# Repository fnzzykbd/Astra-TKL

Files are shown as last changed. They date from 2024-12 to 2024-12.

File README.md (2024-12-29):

# Astra TKL
This is a keyboard design I've made in 2023. It's called Astra because I like space stuff. Top mount WKL TKL, 8° typing angle, 17mm front height (~18mm on inner edge, ~19mm with bumpons). The intended purpose was to make a one-off and then release it to the public once ready. The one-off had a few kinks, however, and another proto means spending more money.

This release includes the original prototyped design with one tweak (see design history), a fully updated design that would've been the second protoype (one day!) and naturally, since this is an open source release, the Fusion 360 .f3d source files with complete history for both versions.

Feel free to use the files to your hearts content in accordance with the license. I am not liable for anything, files are provided as is.

And since I am a curious fellow, if you do something with these files and order something, would be cool to let me know on Discord @fnzzy.
***
DESIGN HISTORY

Prototype was made with top mount + O-ring mount. Case bottom design didn't allow for the O-ring to work, forgot to check. My bad. The prototype had a ping issue due to a slightly warped top case, so I've used it with either the four corner screws only or with heavy force break. Doing either made it sound great.

Provided prototype files have the O-ring mount removed, since it didn't work, everything else is unchanged.

Provided updated design also removed the four centre screws as those made the prototype ping and didn't contribute to the assembly in any critical way. Some internal radii on the weight and the surrounding dish have been changed. Cable channel has been widened and chamfer adjusted to match with other internal chamfers. The updated design has not yet been prototyped.
***
The keyboard has been designed around and proven to work with the [Lysol XYZ DBoard](https://github.com/lyso1/Lysol-XYZ-DBoard) and the [daji Otus Engineering 87.5 1.2mm PCB](https://dajikeyboards.com/products/otus-engineering-87-5-pcb). If you're using another PCB, please make sure it fits.

Special thanks to ankit for providing me with free daughterboards to use with this board. Absolute legend considering that I am a complete stranger to him.

| Part  | Link |
| --- | --- |
| Case screw M3x10mm low profile  | https://www.mcmaster.com/products/screws/socket-head-screws~/thread-size~m3/length~10-mm/  |
| Plate screw M2.5x5mm | https://www.mcmaster.com/products/screws/socket-head-screws~/thread-size~m3/length~5-mm/  |
| Weight screw M3x6mm countersink | https://www.mcmaster.com/products/screws/flat-head-screws~/thread-size~m3/length~6-mm/  |
| Toblerone screw M2.5x6mm countersink | https://www.mcmaster.com/products/screws/flat-head-screws~/length~6-mm/thread-size~m2-5/  |
| Daughterboard screw M3x4mm ultra low profile | https://www.mcmaster.com/products/screws/socket-head-screws~/thread-size~m3/length~4-mm/socket-head-profile~ultra-low/  |
| Bumpons | SJ5302, Bumpon hole is 8.3mm to fit my Unikorn style bumpons I got off aliexpress, which I measured. You might see some gaps around a 3M 8mm Bumpon |

***

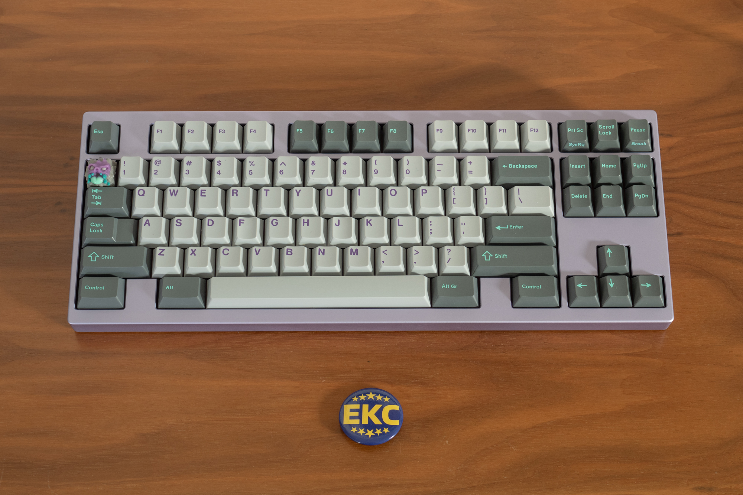
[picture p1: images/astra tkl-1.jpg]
astra-1

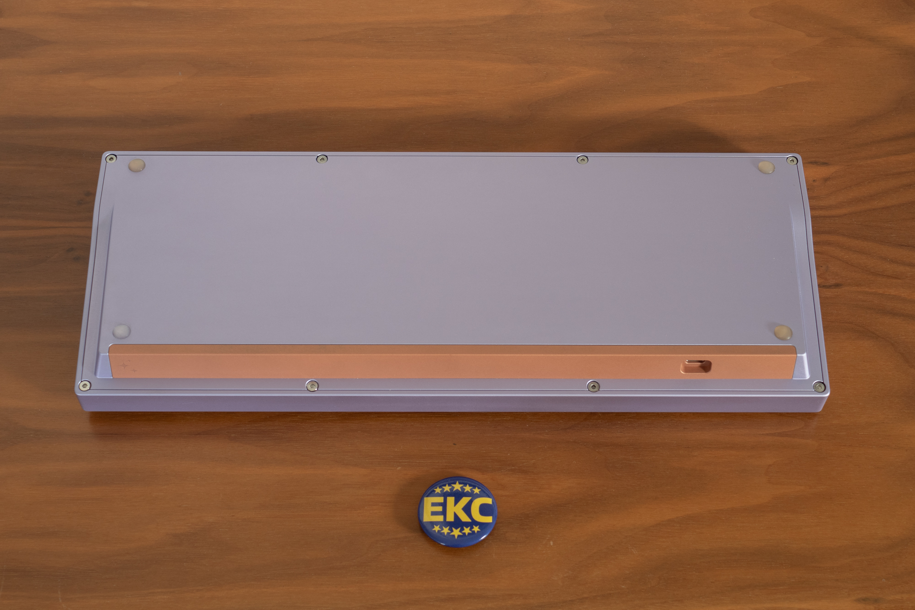
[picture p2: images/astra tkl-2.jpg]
astra-2

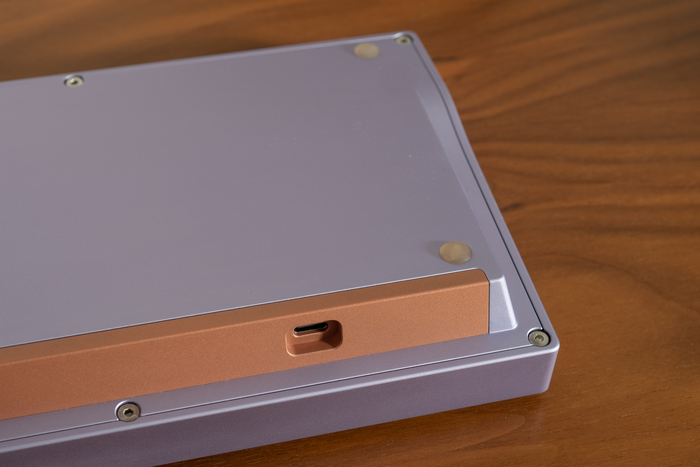
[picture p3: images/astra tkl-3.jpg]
astra-3

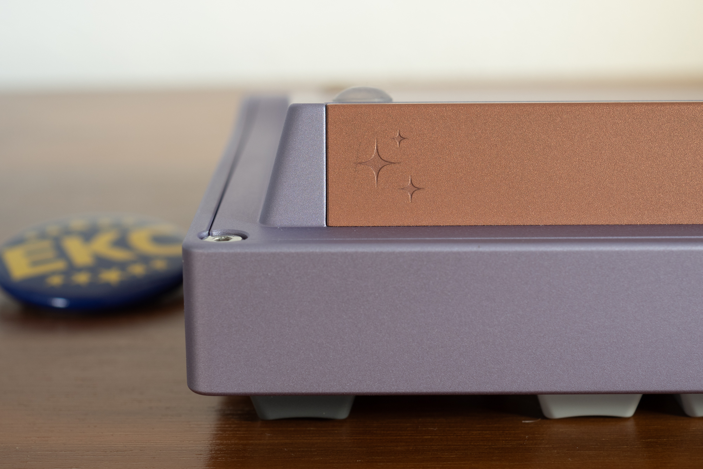
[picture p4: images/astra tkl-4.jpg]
astra-4

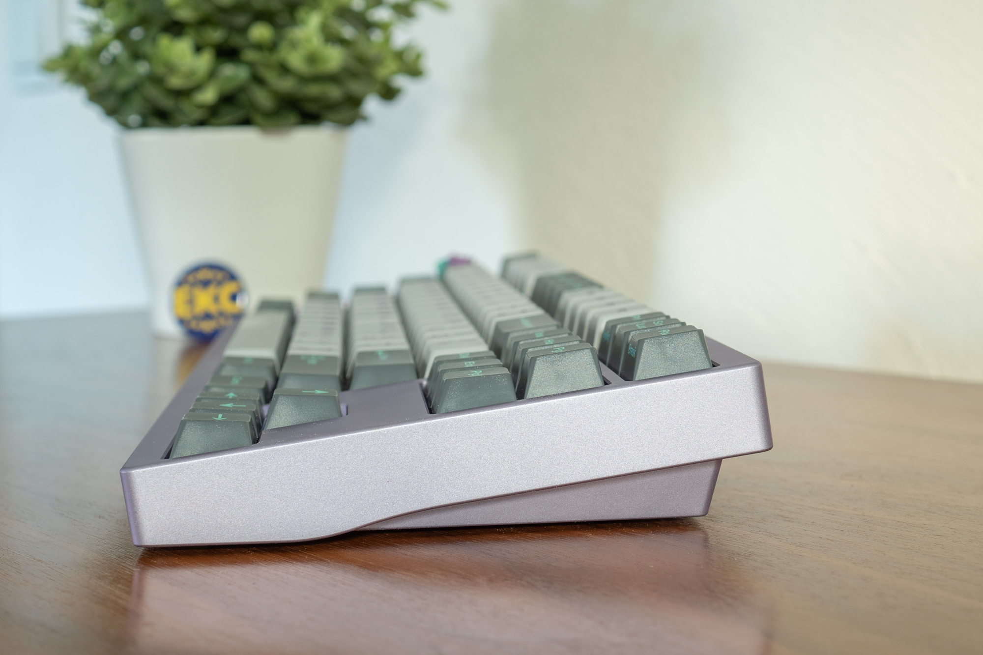
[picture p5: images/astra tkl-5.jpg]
astra-5

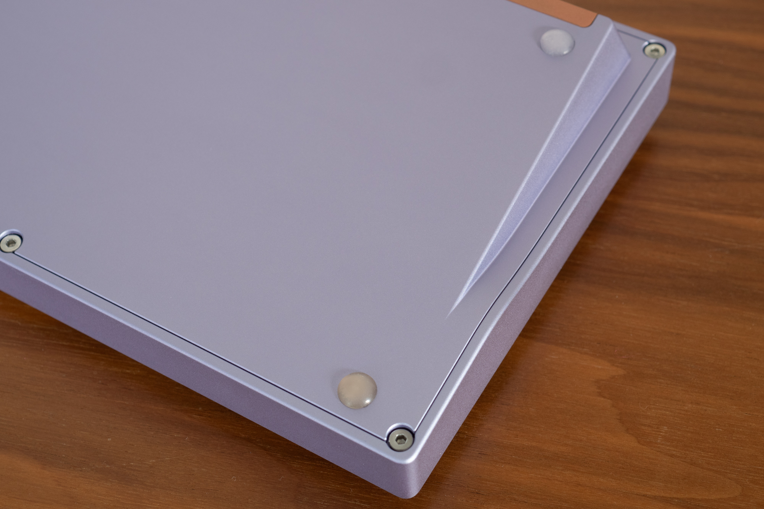
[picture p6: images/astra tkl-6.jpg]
astra-6

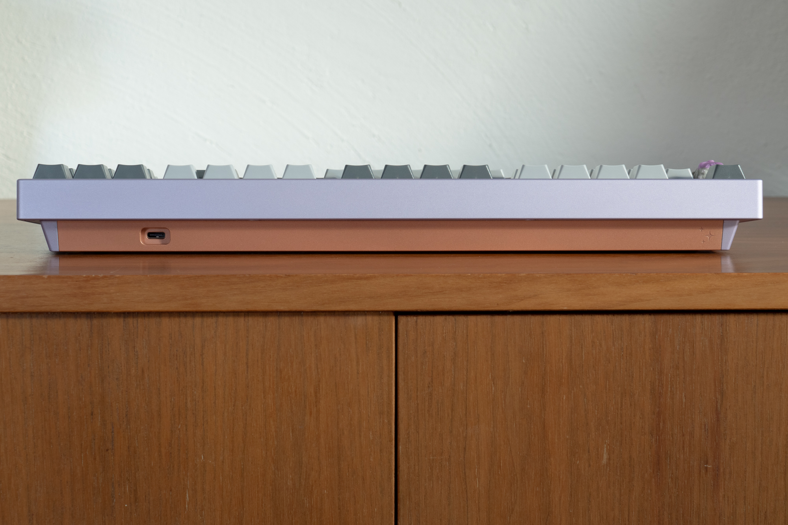
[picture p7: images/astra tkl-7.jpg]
astra-6

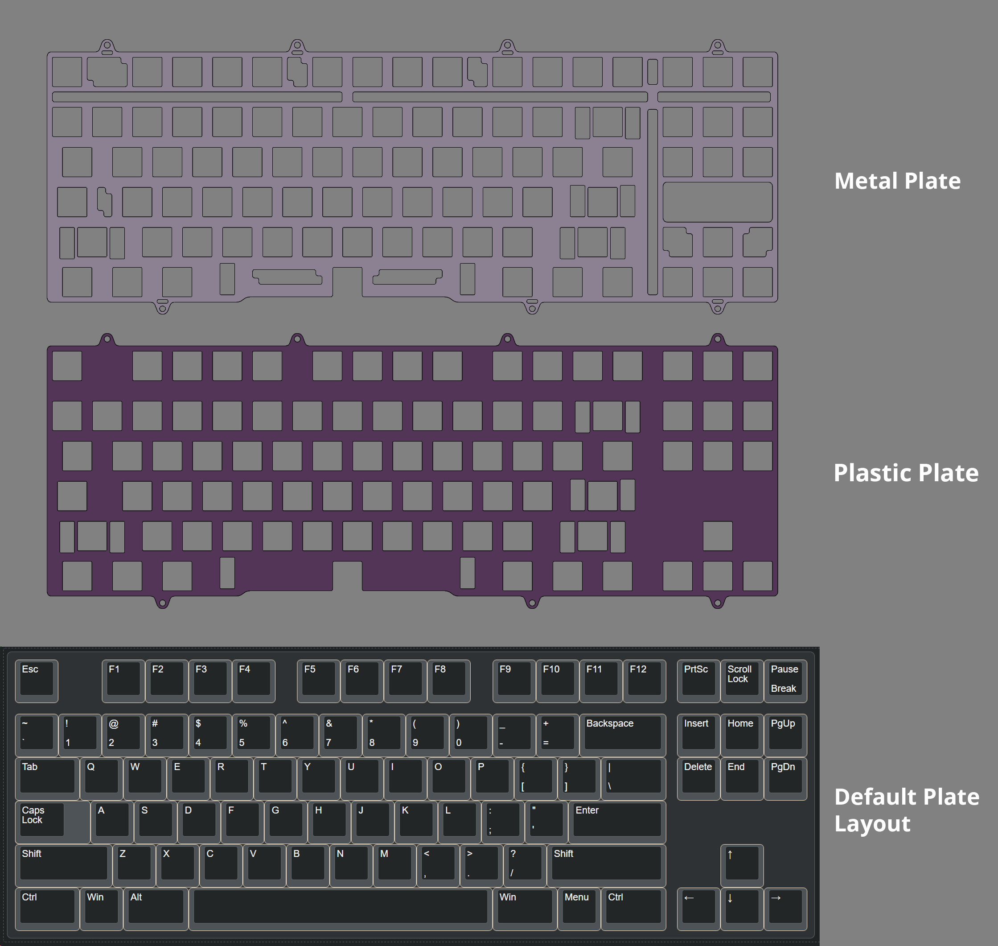
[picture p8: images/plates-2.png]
plates

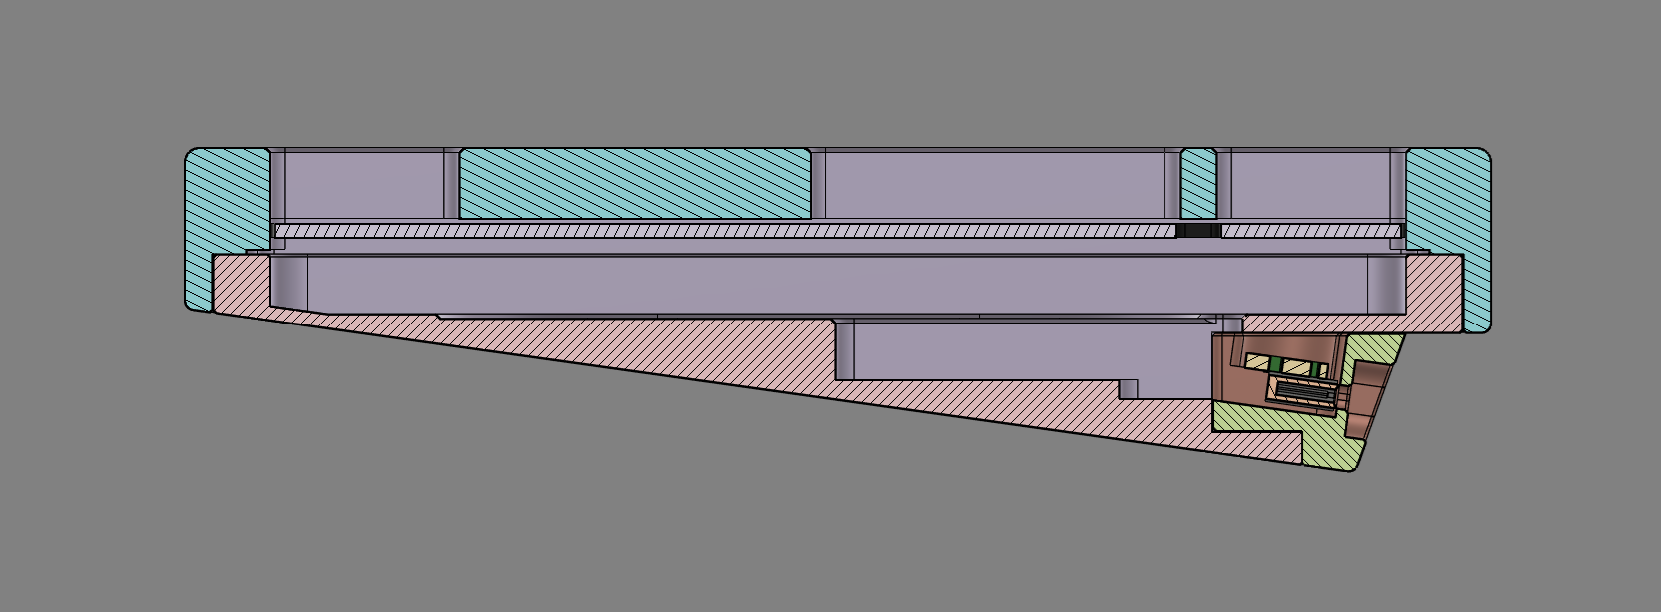
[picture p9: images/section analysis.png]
section


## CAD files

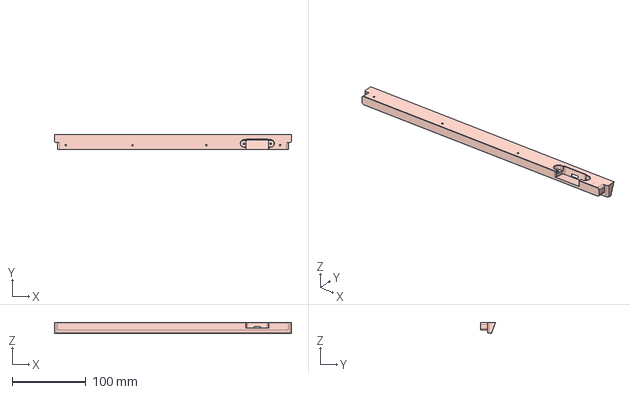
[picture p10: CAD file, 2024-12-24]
Original Prototype/ASTRA_TOBLERONE_COPPER.step
321.2 x 20.3 x 14.6 mm

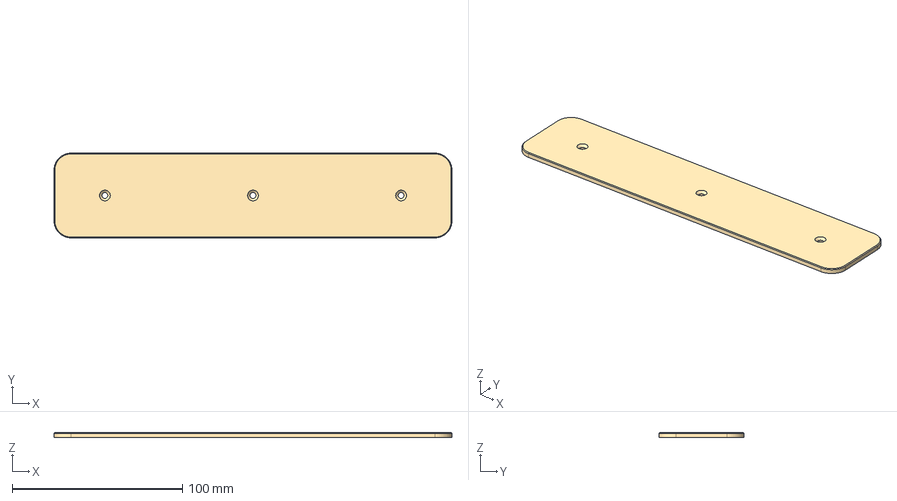
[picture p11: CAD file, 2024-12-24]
Updated Revision/Astra_weight_inner.step
233.7 x 49.8 x 3.00 mm

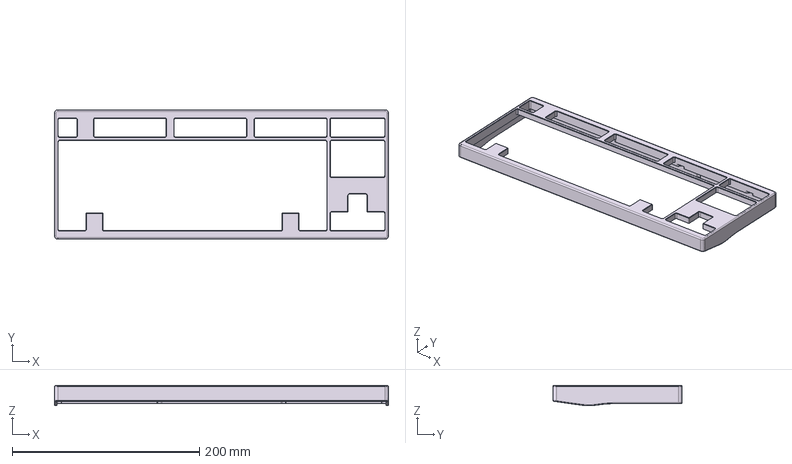
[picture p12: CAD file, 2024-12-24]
Original Prototype/ASTRA_TOP.step
356.6 x 138.0 x 21.9 mm

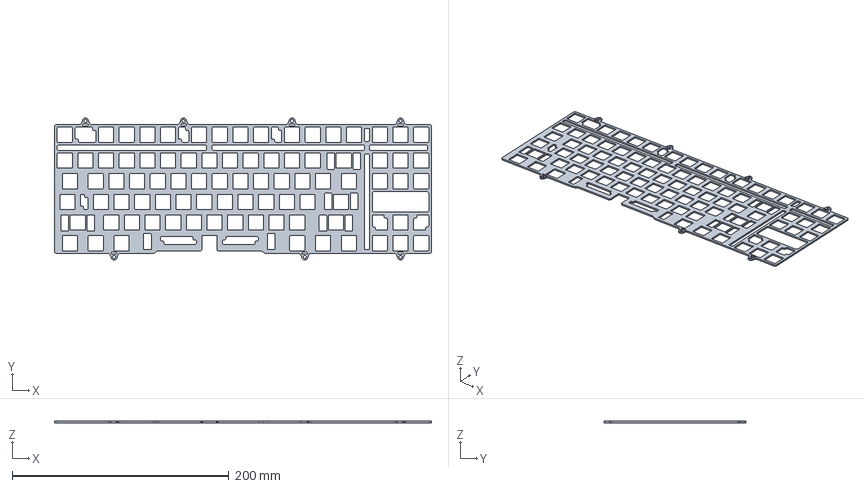
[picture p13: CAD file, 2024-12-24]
Original Prototype/ASTRA_PLATE_ALU5052.step
347.7 x 131.0 x 1.50 mm

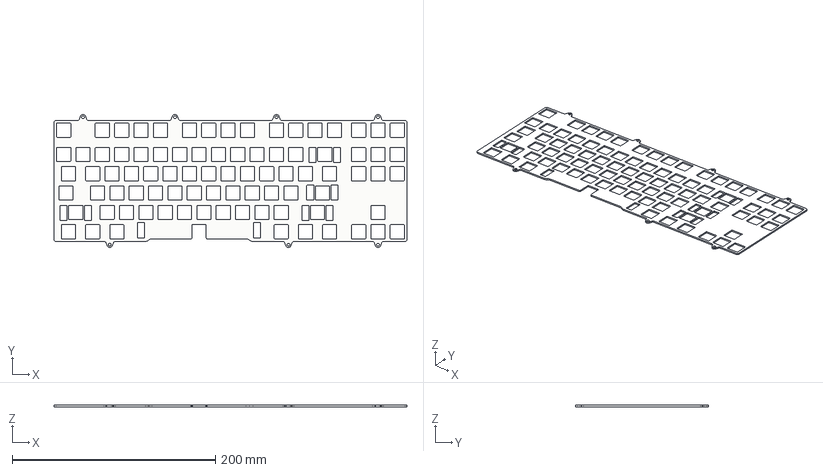
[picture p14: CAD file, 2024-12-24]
Updated Revision/Astra_plate_plastic.step
347.7 x 131.0 x 1.50 mm

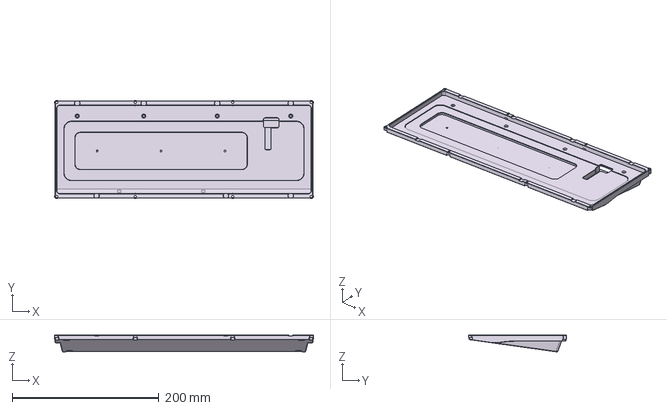
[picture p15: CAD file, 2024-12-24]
Original Prototype/ASTRA_BOTTOM.step
352.4 x 133.8 x 23.0 mm

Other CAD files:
Original Prototype/ASTRA_WEIGHT_BRASS.step
Updated Revision/Astra_toblerone.step
Updated Revision/Astra_top.step
Updated Revision/Astra_plate_metal.step
Original Prototype/ASTRA_PLATE_PC.step
Updated Revision/Astra_bottom.step

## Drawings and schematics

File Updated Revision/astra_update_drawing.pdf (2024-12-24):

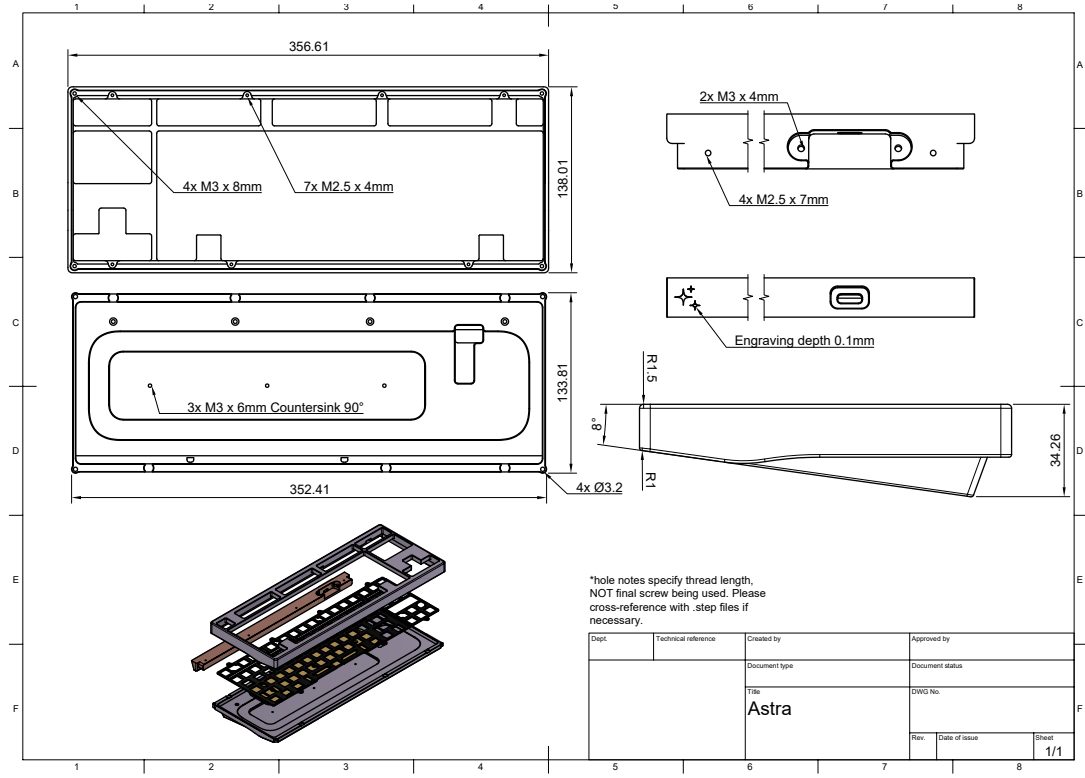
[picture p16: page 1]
8 BCDEF; ABCDEF Dept.; Technical reference; Created by; Approved by Document type; Document status Title; DWG No. Rev.; Date of issue; Sheet 1/1 Astra ³⁵⁶.61; 34.26 3x M3 x 6mm Countersink 90° 2x M3 x 4mm 4x Ø3.2; R1.5 R1 Engraving depth 0.1mm

133.81 352.41 4x M2.5 x 7mm *hole notes specify thread length,

NOT final screw being used. Please
cross-reference with .step files if
necessary.

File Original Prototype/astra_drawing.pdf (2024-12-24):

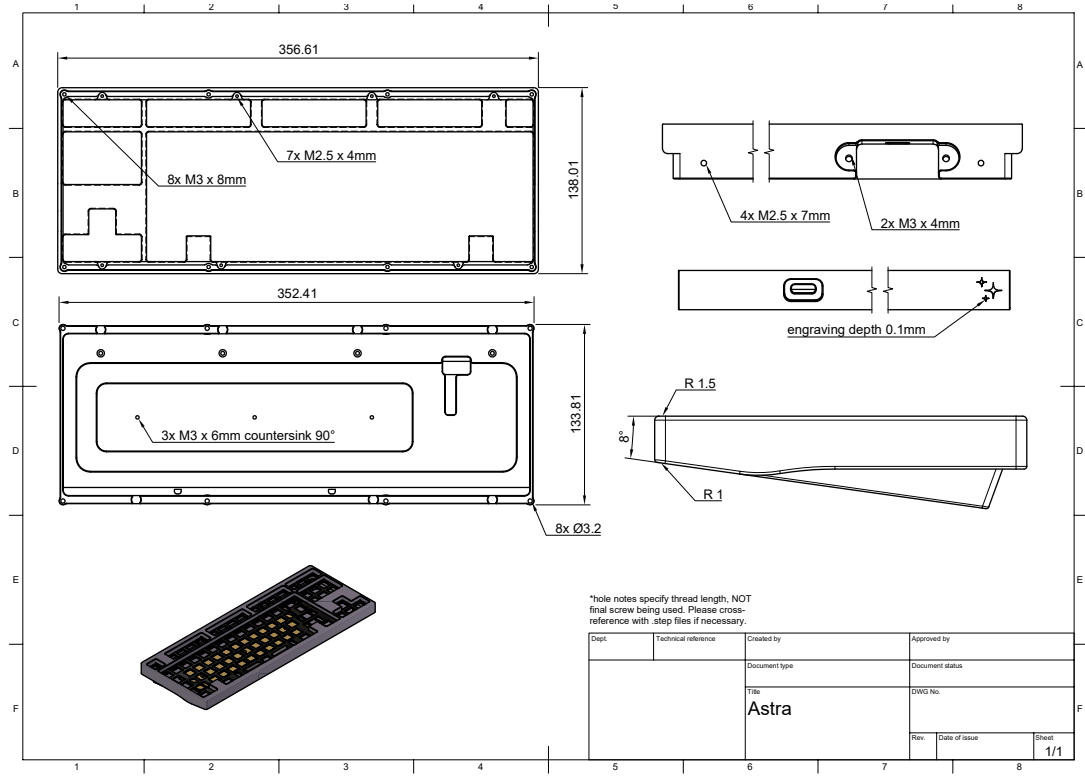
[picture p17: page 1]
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

8° R 1.5R 1 4x M2.5 x 7mm *hole notes specify thread length, NOT

133.81 3x M3 x 6mm countersink 90° 8x Ø3.2 2x M3 x 4mm engraving depth 0.1mm

final screw being used. Please cross-
reference with .step files if necessary.

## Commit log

2024-12-27 Delete images/plates.png
    typo
2024-12-29 Update README.md
    screw info
